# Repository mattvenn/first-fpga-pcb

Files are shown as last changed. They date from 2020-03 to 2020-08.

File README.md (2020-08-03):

# Aim

* Make my first PCB with an FPGA
* Keep it super simple and cheap
* Configured by on-board FLASH or direct with a Raspberry Pi
* 6 PMODs, 2 buttons, 2 LEDs, FLASH for configuration bitstreams.

There is also an ECP5 version of this board: https://github.com/mattvenn/basic-ecp5-pcb

# What a Lattice iCE40 FPGA needs

* A clock input. Has to be provided by an oscillator, it doesn't have a crystal driver.
* 1.2v core supply for the internal logic.
* 2.5v non volatile memory supply. Can be provided via a voltage drop over a diode from 3.3v.
* IO supply for the IO pins, different banks of IO can have different supplies. This design uses 3.3v for all banks.
* Get configured over SPI interface. This can be done directly by a microcontroller or a computer, or the bitstream can be programmed into some FLASH, and the FPGA will read it at boot. If FLASH isn't provided then the bitstream needs to be programmed at every power up or configuration reset. 
* Decoupling capacitors for each IO bank.

# PCB

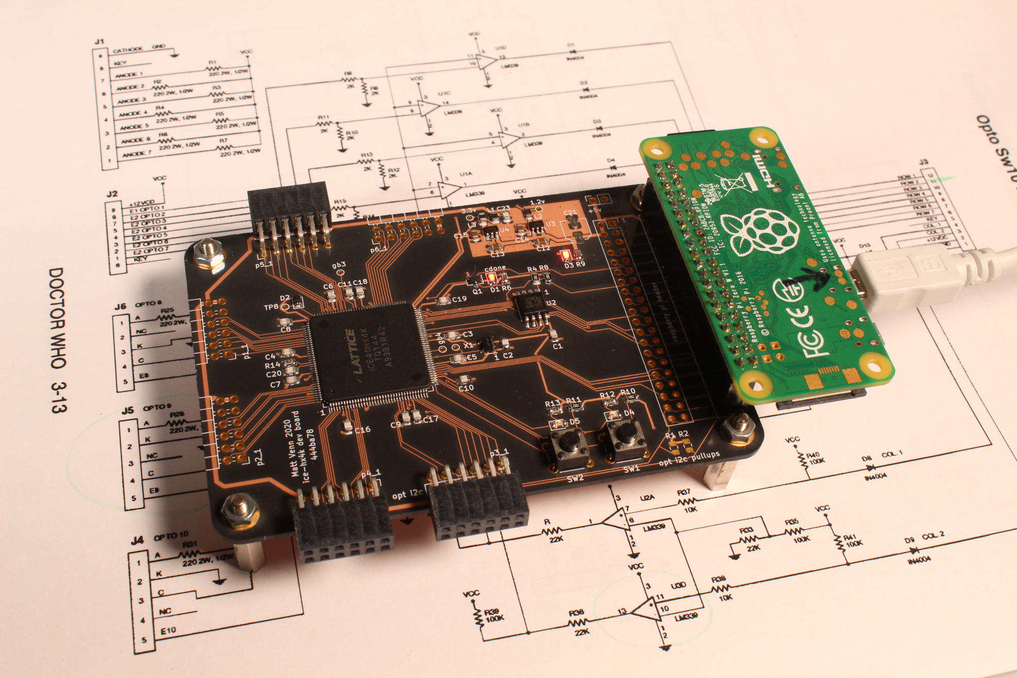
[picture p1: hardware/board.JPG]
board


* [Schematic](hardware/schematic.pdf)
* [OHSPark project](https://oshpark.com/shared_projects/wwMxCKlp) or [Gerbers](hardware/first-fpga-pcb-2020-03-09-fab.zip)
* Cheap, 2 layer board. Probably not so good for fast signals.

# BOM

* FPGA iCE40-HX4K-TQ144 (8k accessible with Icestorm tools)
* 3.3v reg TLV73333PDBVT
* 1.2v reg TLV73312PDBVT
* 12MHz oscillator SIT2001BI-S2-33E-12.000000G
* 16MB FLASH IS25LP016D-JBLE (optional).

# Test

See the [test program](test/top.v). This makes a nice pulsing effect on LED2, and LED1 is the slow PWM clock.
The buttons increase or decrease pulsing speed.

    make prog

Yosys and NextPNR are used to create the bitstream and then it's copied to the Raspberry Pi specified
by PI_ADDR in the [Makefile](test/Makefile). 

[Fomu-Flash](https://github.com/im-tomu/fomu-flash) is used to flash the SPI memory, or program the FPGA directly.

# HW V3: bfcbcf7

* fixed mistakenly removed pullups on io2/3 on SPI flash. This made the system vulnerable to noise while FPGA was reading flash.

# HW V2: 444ba78

* removed a few unnecessary pullups on SPI lines - introduced a fault see HW V3.
* connect 4 general purpose pins between Pi & FPGA
* connect additional CS1 pin for SPI comms with Pi
* breakout all Pi pins on separate pins
* shrink board in y axis slightly for even holes and to fit larger Pi boards
* Allow an I2C connection between Pi & FPGA, broken out on pmod p3:
    * Place optional 4k7 pullup resistors R1&R2
    * Setup bitbanged I2C on Raspi on gpios 20 & 21 (pins 38 & 40)
* used FOMU programming pins so default FOMU programming app will work

# HW V1: d9c7cdf

## Errata

* didn't expose a 2nd CS pin so can't communicate with SPI without removing flash 

My fork of [Fomu-Flash](https://github.com/mattvenn/fomu-flash) is used for programming. Fomu-Flash should be able
to reconfigure the pins used with -g, but I couldn't get this to work, so I hard-coded the right pins in this
fork.

# Inspiration

* https://github.com/OLIMEX/iCE40HX1K-EVB/blob/master/iCE40HX1K-EVB_Rev_B.pdf
* https://github.com/icebreaker-fpga/icebreaker/blob/master/hardware/v1.0e/icebreaker-sch.pdf
* icestick

# Reference

* Family datasheet: http://www.latticesemi.com/view_document?document_id=49312
* Programming/FLASH spec: http://www.latticesemi.com/view_document?document_id=46502
* Pinout: http://www.latticesemi.com/view_document?document_id=49383

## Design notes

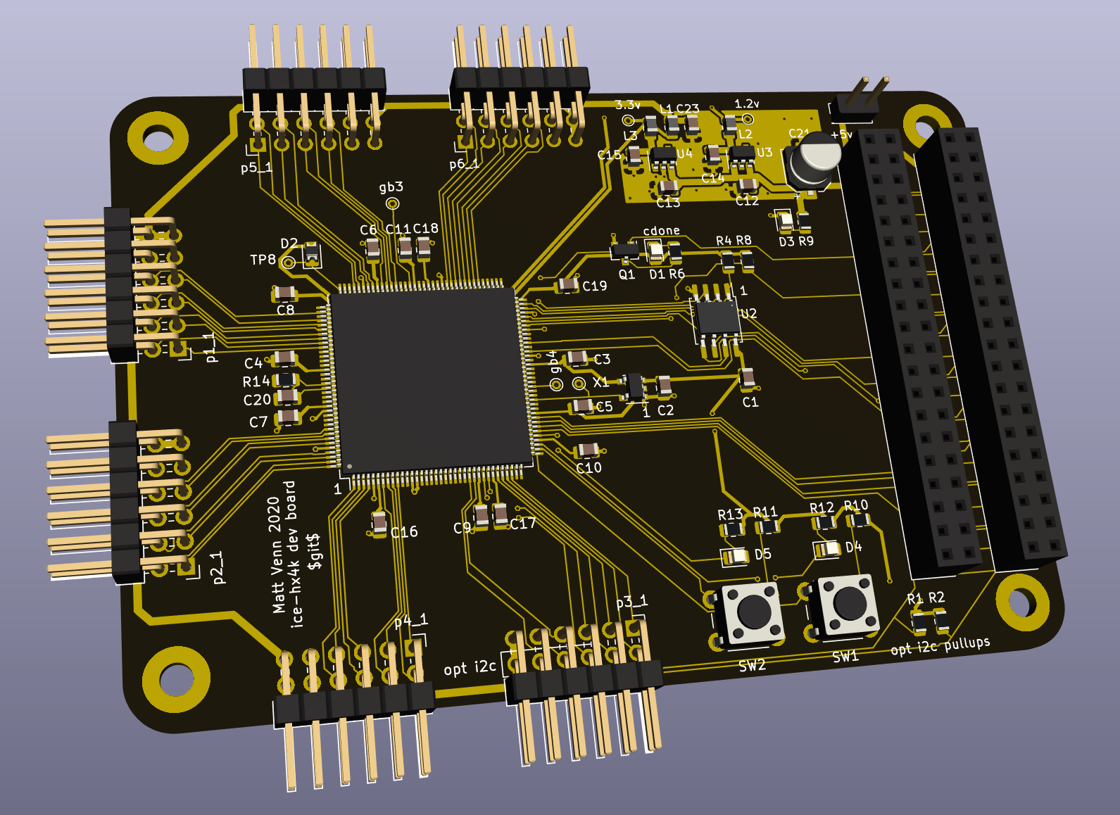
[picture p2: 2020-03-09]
hardware/board.png

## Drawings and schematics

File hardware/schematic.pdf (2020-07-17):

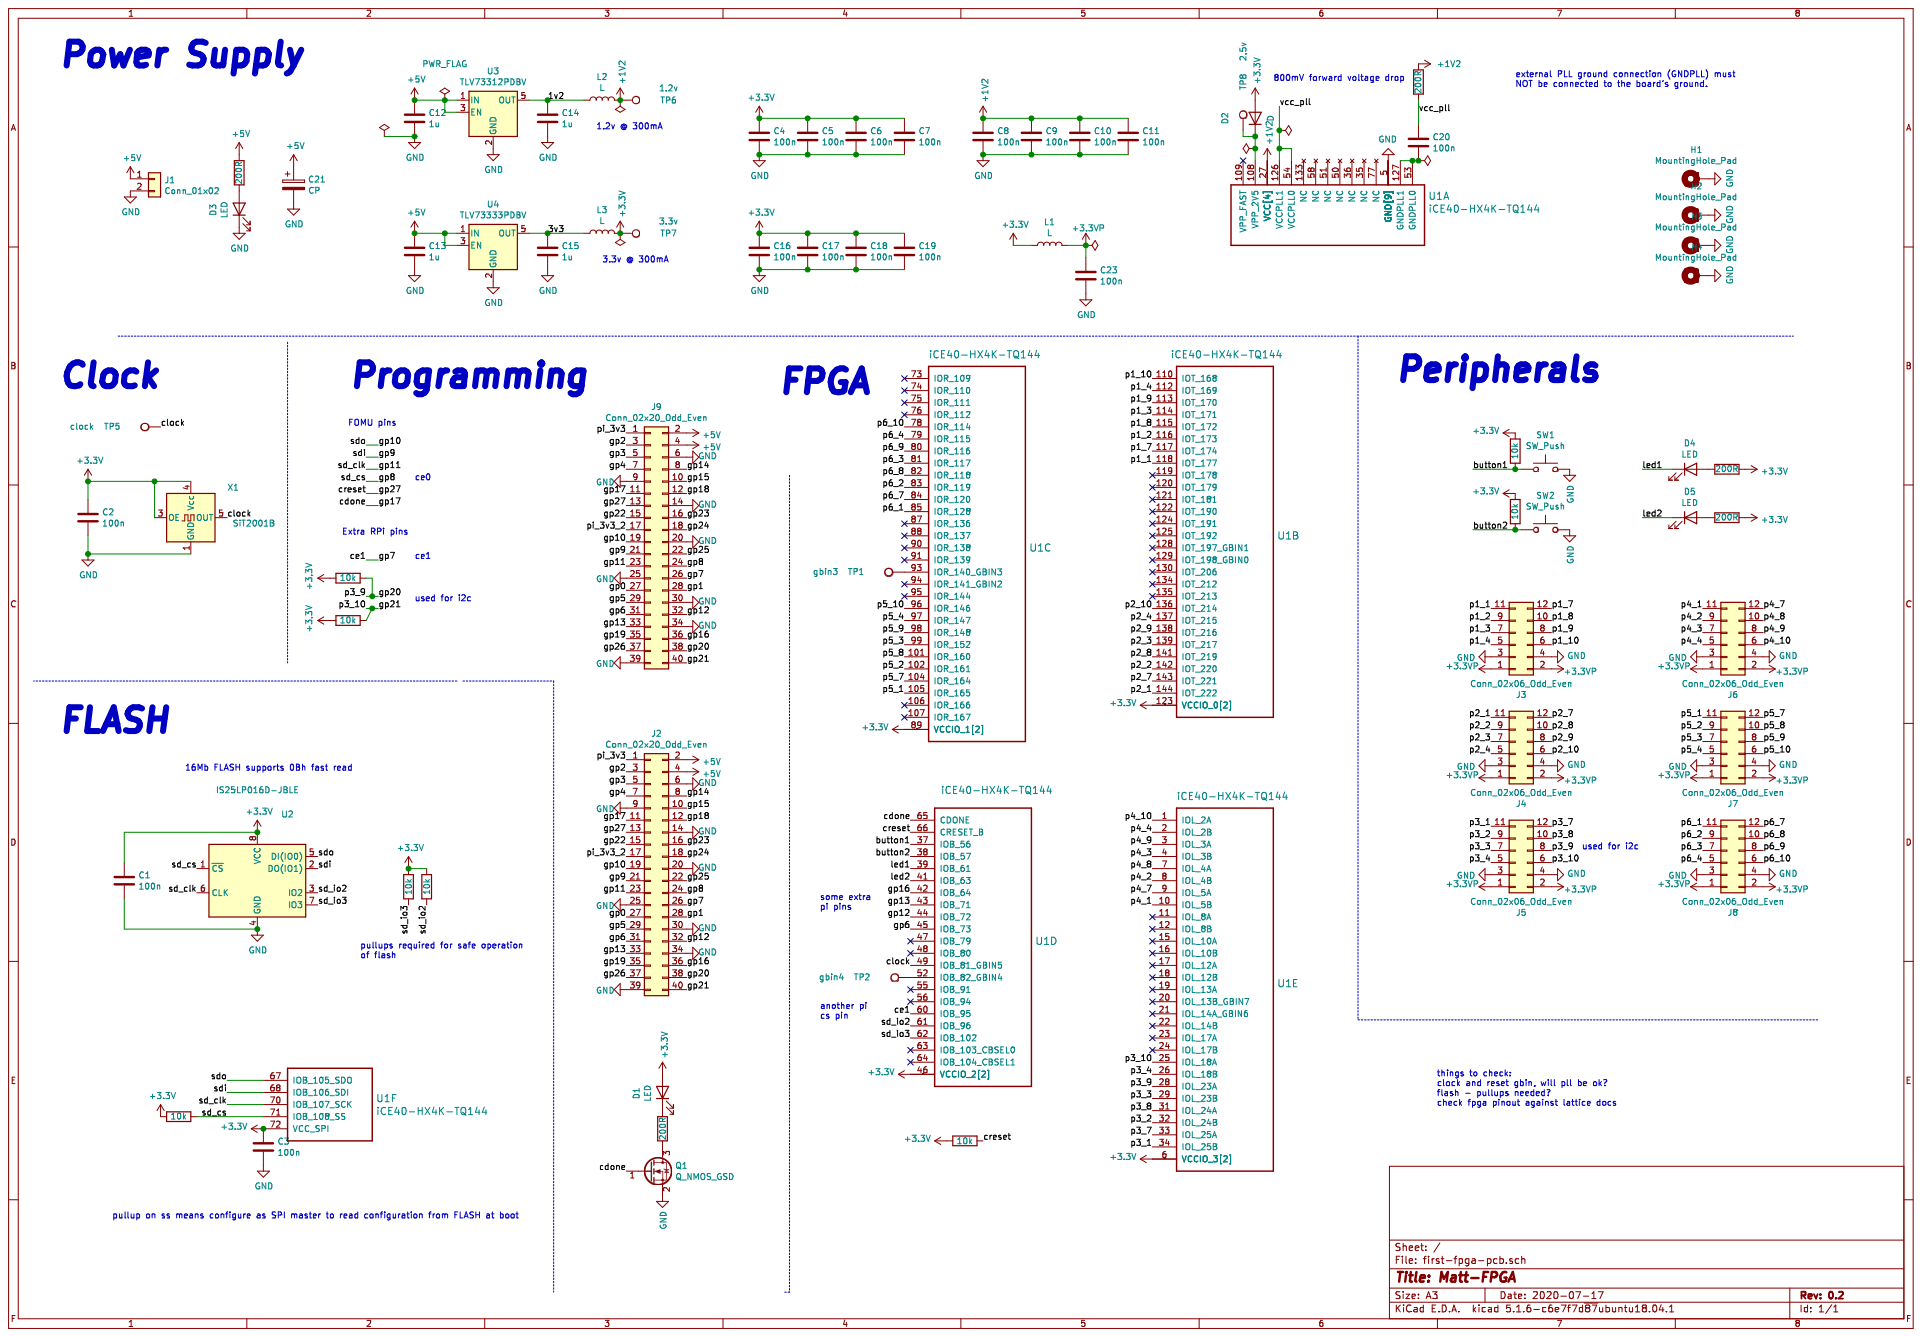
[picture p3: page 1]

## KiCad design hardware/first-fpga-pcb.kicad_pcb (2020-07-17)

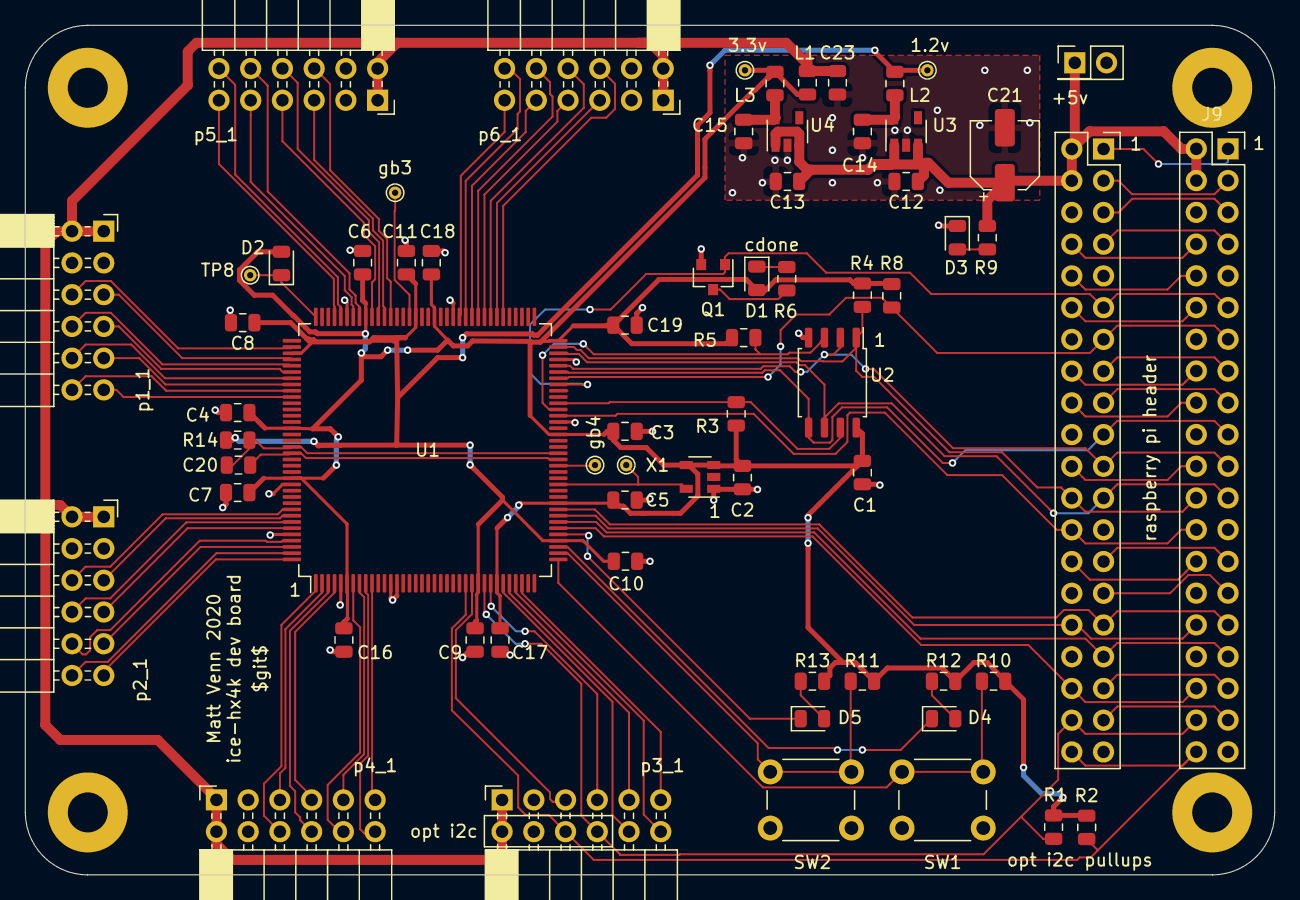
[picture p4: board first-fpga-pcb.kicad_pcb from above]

Board: 2 copper layers, 100.0 x 68.0 mm, 70 parts (0 on the bottom side), 100 nets.

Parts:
C1, C2, C3, C4, C5, C6, C7, C8, C9, C10, C11, C16, C17, C18, C19, C20, C23: 100n; C_0805_2012Metric
C12, C13, C14, C15: 1u; C_0805_2012Metric
C21: CP; CP_Elec_5x5.4
D1, D3, D4, D5: LED; LED_0805_2012Metric
D2: D; D_0805_2012Metric
H1, H2, H3, H4: MountingHole_Pad; MountingHole_3.2mm_M3_Pad
J1: Conn_01x02; PinHeader_2x01_P2.54mm_Vertical
J2, J9: Conn_02x20_Odd_Even; PinSocket_2x20_P2.54mm_Vertical
J3, J4, J5, J6, J7, J8: Conn_02x06_Odd_Even; PinSocket_2x06_P2.54mm_Horizontal
L1, L2, L3: L; L_0805_2012Metric
Q1: Q_NMOS_GSD; SOT-23
R1, R2, R3, R4, R5, R8, R10, R11: 10k; R_0805_2012Metric
R6, R9, R12, R13, R14: 200R; R_0805_2012Metric
SW1, SW2: SW_Push; SW_PUSH_6mm
TP1: gbin3; TestPoint_THTPad_D1.0mm_Drill0.5mm
TP2: gbin4; TestPoint_THTPad_D1.0mm_Drill0.5mm
TP5: clock; TestPoint_THTPad_D1.0mm_Drill0.5mm
TP6: 1.2v; TestPoint_THTPad_D1.0mm_Drill0.5mm
TP7: 3.3v; TestPoint_THTPad_D1.0mm_Drill0.5mm
TP8: 2.5v; TestPoint_THTPad_D1.0mm_Drill0.5mm
U1: iCE40-HX4K-TQ144; TQFP-144_20x20mm_P0.5mm
U2: IS25LP016D-JBLE; SOIC-8_5.23x5.23mm_P1.27mm
U3: TLV73312PDBV; SOT-23-5
U4: TLV73333PDBV; SOT-23-5
X1: SiT2001B; SOT-23-5

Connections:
+1V2: C8.1, C9.1, C10.1, C11.1, L2.2, R14.2, TP6.1, U1.27, U1.40, U1.92, U1.111
+3.3VP: C23.1, J3.1, J3.2, J4.1, J4.2, J5.1, J5.2, J6.1, J6.2, J7.1, J7.2, J8.1, J8.2, L1.2
+3V3: C1.1, C2.1, C3.1, C4.1, C5.1, C6.1, C7.1, C16.1, C17.1, C18.1, C19.1, D1.2, D2.2, L1.1, L3.2, R1.1, R2.1, R3.1, R4.1, R5.1, R8.2, R10.2, R11.2, R12.2, R13.2, TP7.1, U1.6, U1.30, U1.46, U1.57, U1.72, U1.89, U1.100, U1.123, U1.131, U2.8, X1.3, X1.4
+5V: C12.1, C13.1, C21.1, J1.1, J2.2, J2.4, J9.2, J9.4, R9.2, U3.1, U3.3, U4.1, U4.3
/1v2: C14.1, L2.1, U3.5
/3v3: C15.1, L3.1, U4.5
/button1: R10.1, SW1.1, U1.37
/button2: R11.1, SW2.1, U1.38
/cdone: J2.11, J9.11, Q1.1, U1.65
/ce1: J2.26, J9.26, U1.60
/clock: TP5.1, U1.49, X1.5
/creset: J2.13, J9.13, R8.1, U1.66
/gp0: J2.27, J9.27
/gp1: J2.28, J9.28
/gp2: J2.3, J9.3
/gp3: J2.5, J9.5
/gp4: J2.7, J9.7
/gp5: J2.29, J9.29
/gp6: J2.31, J9.31, U1.45
/gp8: J2.24, J9.24, R4.2, U1.71, U2.1
/gp9: J2.21, J9.21, U1.68, U2.2
/gp10: J2.19, J9.19, U1.67, U2.5
/gp11: J2.23, J9.23, U1.70, U2.6
/gp12: J2.32, J9.32, U1.44
/gp13: J2.33, J9.33, U1.43
/gp14: J2.8, J9.8
/gp15: J2.10, J9.10
/gp16: J2.36, J9.36, U1.42
/gp18: J2.12, J9.12
/gp19: J2.35, J9.35
/gp20: J2.38, J5.8, J9.38, R1.2, U1.28
/gp21: J2.40, J5.6, J9.40, R2.2, U1.25
/gp22: J2.15, J9.15
/gp23: J2.16, J9.16
/gp24: J2.18, J9.18
/gp25: J2.22, J9.22
/gp26: J2.37, J9.37
/led1: D4.1, U1.39
/led2: D5.1, U1.41
/p1_1: J3.11, U1.118
/p1_2: J3.9, U1.116
/p1_3: J3.7, U1.114
/p1_4: J3.5, U1.112
/p1_7: J3.12, U1.117
/p1_8: J3.10, U1.115
/p1_9: J3.8, U1.113
/p1_10: J3.6, U1.110
/p2_1: J4.11, U1.144
/p2_2: J4.9, U1.142
/p2_3: J4.7, U1.139
/p2_4: J4.5, U1.137
/p2_7: J4.12, U1.143
/p2_8: J4.10, U1.141
/p2_9: J4.8, U1.138
/p2_10: J4.6, U1.136
/p3_1: J5.11, U1.34
/p3_2: J5.9, U1.32
/p3_3: J5.7, U1.29
/p3_4: J5.5, U1.26
/p3_7: J5.12, U1.33
/p3_8: J5.10, U1.31
/p4_1: J6.11, U1.10
/p4_2: J6.9, U1.8
/p4_3: J6.7, U1.4
/p4_4: J6.5, U1.2
/p4_7: J6.12, U1.9
/p4_8: J6.10, U1.7
/p4_9: J6.8, U1.3
/p4_10: J6.6, U1.1
/p5_1: J7.11, U1.105
/p5_2: J7.9, U1.102
/p5_3: J7.7, U1.99
/p5_4: J7.5, U1.97
/p5_7: J7.12, U1.104
/p5_8: J7.10, U1.101
/p5_9: J7.8, U1.98
/p5_10: J7.6, U1.96
/p6_1: J8.11, U1.85
/p6_2: J8.9, U1.83
/p6_3: J8.7, U1.81
/p6_4: J8.5, U1.79
/p6_7: J8.12, U1.84
/p6_8: J8.10, U1.82
/p6_9: J8.8, U1.80
/p6_10: J8.6, U1.78
/pi_3v3: J2.1, J9.1
/pi_3v3_2: J2.17, J9.17
/sd_io2: R5.2, U1.61, U2.3
/sd_io3: R3.2, U1.62, U2.7
/vcc_pll: C20.1, R14.1, U1.54, U1.126
GND: C1.2, C2.2, C3.2, C4.2, C5.2, C6.2, C7.2, C8.2, C9.2, C10.2, C11.2, C12.2, C13.2, C14.2, C15.2, C16.2, C17.2, C18.2, C19.2, C21.2, C23.2, D3.1, H1.1, H2.1, H3.1, H4.1, J1.2, J2.6, J2.9, J2.14, J2.20, J2.25, J2.30, J2.34, J2.39, J3.3, J3.4, J4.3, J4.4, J5.3, J5.4, J6.3, J6.4, J7.3, J7.4, J8.3, J8.4, J9.6, J9.9, J9.14, J9.20, J9.25, J9.30, J9.34, J9.39, Q1.2, SW1.2, SW2.2, U1.5, U1.13, U1.14, U1.59, U1.69, U1.86, U1.103, U1.132, U1.140, U2.4, U3.2, U4.2, X1.1
unnamed: C20.2, U1.53, U1.127
unnamed: D1.1, R6.1
unnamed: D2.1, TP8.1, U1.108
unnamed: D3.2, R9.1
unnamed: D4.2, R12.1
unnamed: D5.2, R13.1
unnamed: Q1.3, R6.2
unnamed: TP1.1, U1.93
unnamed: TP2.1, U1.52

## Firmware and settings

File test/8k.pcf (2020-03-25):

set_io -nowarn sw1      37
set_io -nowarn sw2      38
set_io -nowarn led1     39
set_io -nowarn led2     41
set_io -nowarn clk      49

set_io -nowarn pmod6_10 78
set_io -nowarn pmod6_4  79
set_io -nowarn pmod6_9  80
set_io -nowarn pmod6_3  81
set_io -nowarn pmod6_8  82
set_io -nowarn pmod6_2  83
set_io -nowarn pmod6_7  84
set_io -nowarn pmod6_1  85

set_io -nowarn gbin3    93

set_io -nowarn pmod5_10 96
set_io -nowarn pmod5_4  97
set_io -nowarn pmod5_9  98
set_io -nowarn pmod5_3  99
set_io -nowarn pmod5_8  101
set_io -nowarn pmod5_2  102
set_io -nowarn pmod5_7  104
set_io -nowarn pmod5_1  105

# extra pins for qspi
set_io -nowarn sd_io2   61
set_io -nowarn sd_io3   62
set_io -nowarn sd_cs    71  # connected to Raspi gpio8  (ce0)
set_io -nowarn sd_sck   70  # connected to Raspi gp11   (clk)
set_io -nowarn sd_sdi   68  # connected to Raspi gpio9  (miso)
set_io -nowarn sd_sdo   67  # connected to Raspi gpio10 (mosi)

# extra GPIO pins for Raspi comms
set_io -nowarn gpio16   42  # connected to Raspi gpio16
set_io -nowarn gpio13   43  # connected to Raspi gpio13
set_io -nowarn gpio12   44  # connected to Raspi gpio12
set_io -nowarn gpio6    45  # connected to Raspi gpio6
set_io -nowarn gpio7    60  # connected to Raspi gpio7  (ce1)

set_io -nowarn pmod1_10 110
set_io -nowarn pmod1_4  112
set_io -nowarn pmod1_9  113
set_io -nowarn pmod1_3  114
set_io -nowarn pmod1_8  115
set_io -nowarn pmod1_2  116
set_io -nowarn pmod1_7  117
set_io -nowarn pmod1_1  118

set_io -nowarn pmod2_10 136
set_io -nowarn pmod2_4  137
set_io -nowarn pmod2_9  138
set_io -nowarn pmod2_3  139
set_io -nowarn pmod2_8  141
set_io -nowarn pmod2_2  142
set_io -nowarn pmod2_7  143
set_io -nowarn pmod2_1  144

set_io -nowarn pmod4_10 1
set_io -nowarn pmod4_4  2
set_io -nowarn pmod4_9  3
set_io -nowarn pmod4_3  4
set_io -nowarn pmod4_8  7
set_io -nowarn pmod4_2  8
set_io -nowarn pmod4_7  9
set_io -nowarn pmod4_1  10

set_io -nowarn pmod3_10 25 # can put a pull up on R2 for I2C. Connected to Raspi gpio21. Need to setup bitbanged I2C on Raspi on this pin.
set_io -nowarn pmod3_4  26
set_io -nowarn pmod3_9  28 # can put a pull up on R1 for I2C. Connected to Raspi gpio20. Need to setup bitbanged I2C on Raspi on this pin.
set_io -nowarn pmod3_3  29
set_io -nowarn pmod3_8  31
set_io -nowarn pmod3_2  32
set_io -nowarn pmod3_7  33
set_io -nowarn pmod3_1  34

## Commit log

2019-12-30 neaten schematic
    [first-fpga-pcb.kicad_pcb, first-fpga-pcb.sch]
2019-12-30 schematic pdf
2019-12-30 changed to 144 pin package for PLL, added more PMODs, chose FLASH part, updated README
    [first-fpga-pcb.kicad_pcb, first-fpga-pcb.sch]
2019-12-30 use submodule
    [first-fpga-pcb.kicad_pcb, first-fpga-pcb.sch]
2019-12-30 updated schematic
    [first-fpga-pcb.sch]
2019-12-30 fixed PLL gnd connected to board gnd
    [first-fpga-pcb.sch]
2019-12-30 starting layout
    [first-fpga-pcb.kicad_pcb, first-fpga-pcb.sch]
2019-12-31 change to 4k and finish routing
    [first-fpga-pcb.kicad_pcb, first-fpga-pcb.sch]
2019-12-31 update schematic and readme
2019-12-31 added raspi header, fattened psu traces, moved psu to top
    [first-fpga-pcb.kicad_pcb, first-fpga-pcb.sch]
2020-01-01 changed flash orientation for better routing, fixed upside down header
    [first-fpga-pcb.kicad_pcb, first-fpga-pcb.sch]
2020-01-10 hard coded reset pin
2020-01-10 gpio numbering notes on Raspi Header
    [first-fpga-pcb.sch]
2020-01-10 add pin numbers for all pmods
2020-01-10 spi pins
2020-01-10 update schematic with raspi gpio pin notes
2020-01-10 added gerbers
    [first-fpga-pcb.kicad_pcb, first-fpga-pcb.sch]
2020-01-10 move board png
2020-01-10 add schematic to readme
2020-01-10 add link to gerbers and ohspark
2020-01-17 pwm led
2020-03-09 fixed a few things and added features as detailed in README.md
    [first-fpga-pcb.kicad_pcb, first-fpga-pcb.sch]
2020-03-09 added new gerbers
2020-03-24 change pmod to female
    [first-fpga-pcb.kicad_pcb, first-fpga-pcb.sch]
2020-03-24 pwm_width as a -D variable
2020-03-25 make gamma configurable in Makefile, show PWM slow clock on LED1
2020-03-25 updated schematic, linked new gerbers and oshpark project in README
2020-07-17 fixed missing hold resistor
    [first-fpga-pcb.kicad_pcb, first-fpga-pcb.sch]
2020-07-17 updated schematic and added git ref to readme of v3 hw
